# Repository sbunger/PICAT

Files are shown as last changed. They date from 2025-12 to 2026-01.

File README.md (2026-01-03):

# PICAT
PiCat is a custom devboard created with help from HackClub! The board is completely custom, running on an RP2040 and is connected to 16MB of flash memory and two 5mm LEDs that can be controlled. PCBs were created in KICAD and renders were created using Blender (renders have out of date silkscreen, but should otherwise be identical to the pcb).

I created this project gain experience working on PCBs while creating a product I will use. I plan to use at least one of the two devboards as an LED controller in a 3d printed lamp, and the other one will be used for a future project. 

The devboard can be controlled through circuitpython and arduino. Right now, I am using circuitpython to make two LEDs blink (example file in code folder).

## Photos!

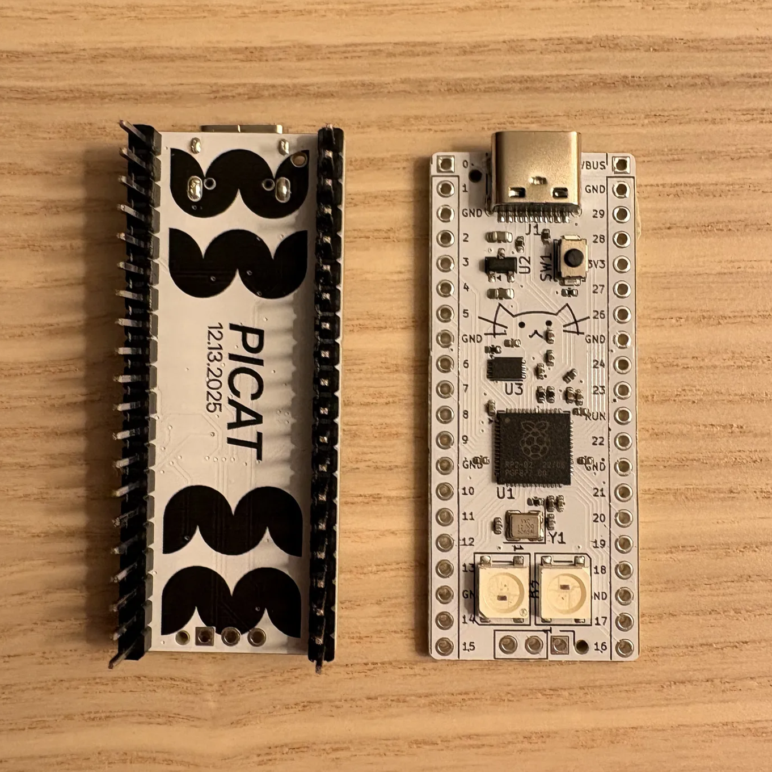
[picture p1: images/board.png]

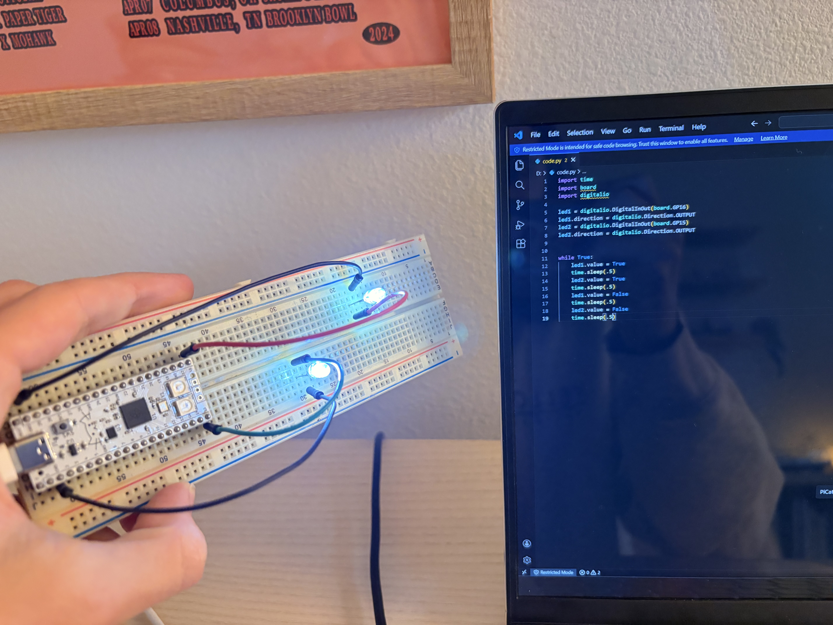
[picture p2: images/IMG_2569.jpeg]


## PCB and Schematics
PCBs were created competely by hand in KICAD.

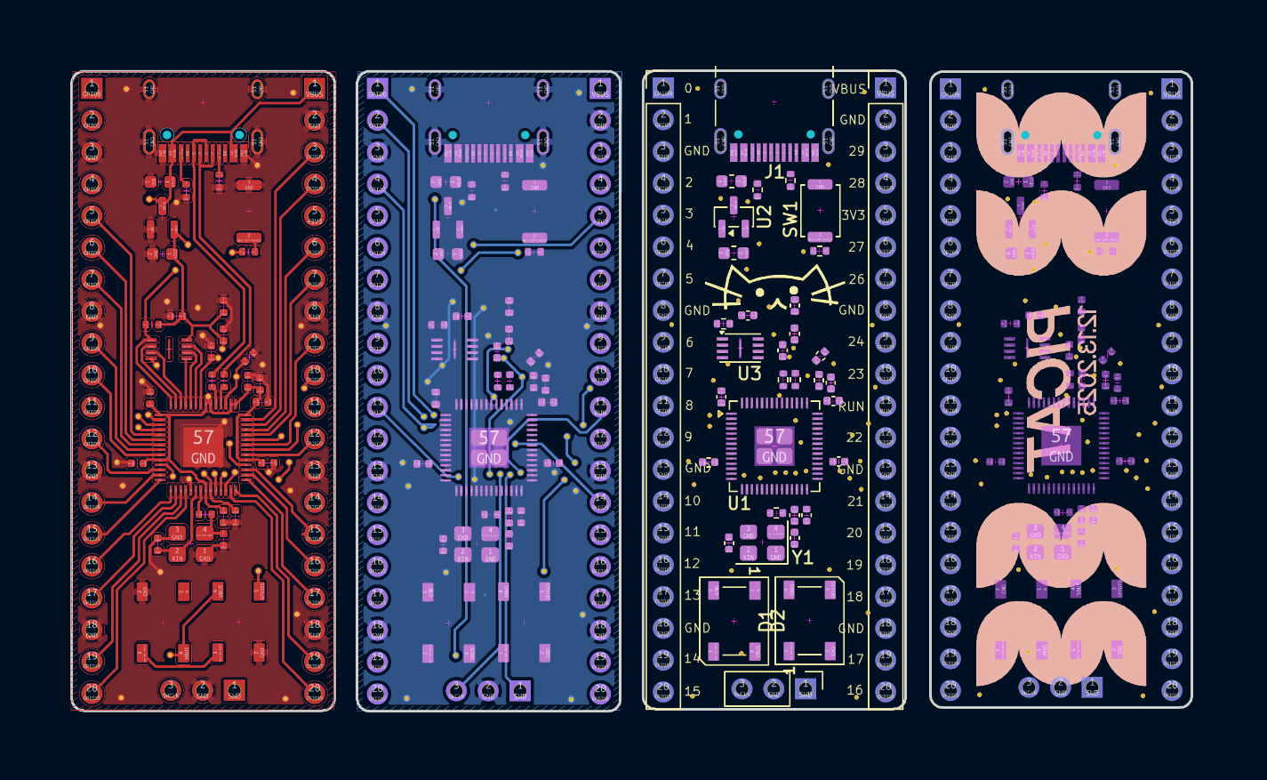
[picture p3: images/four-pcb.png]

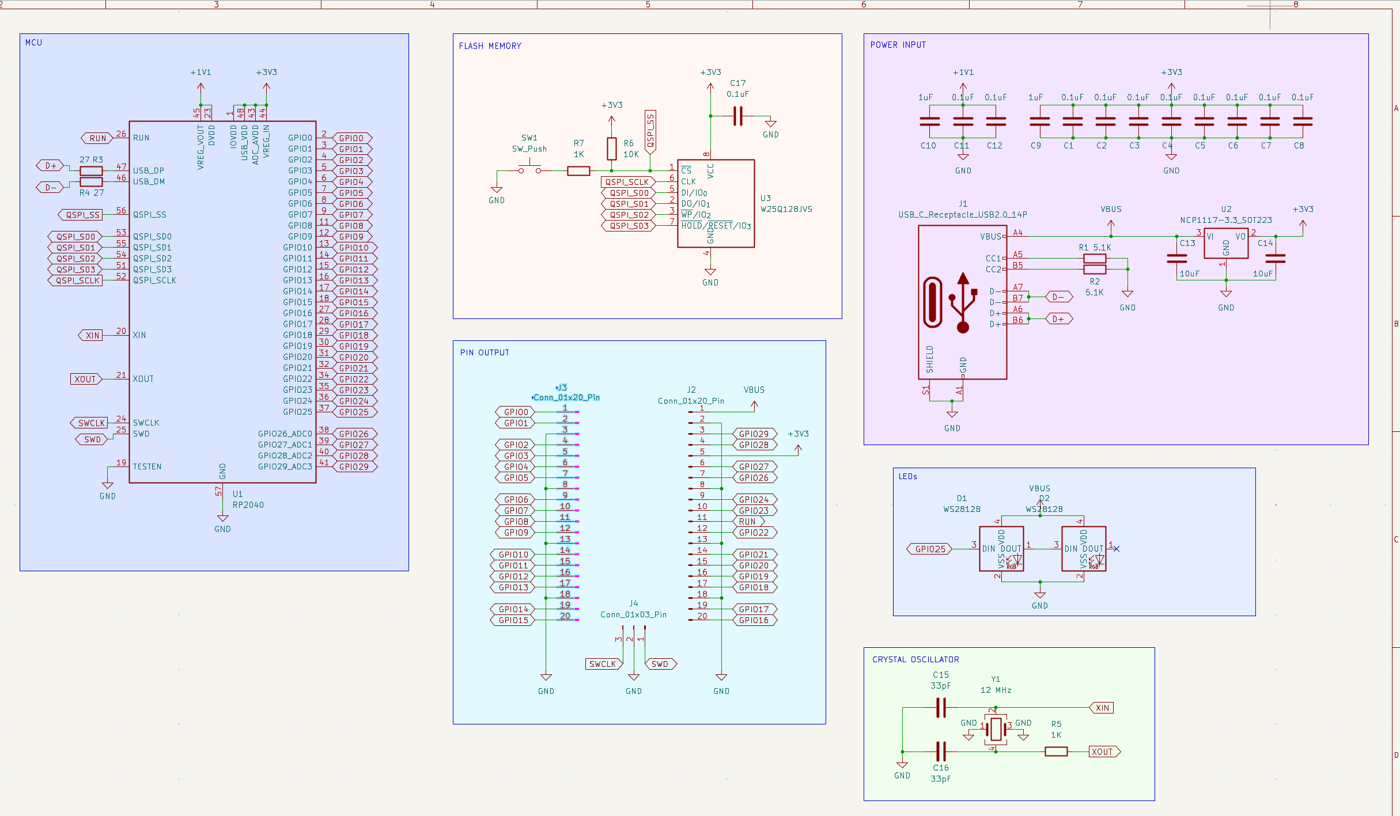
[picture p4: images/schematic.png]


## Renders

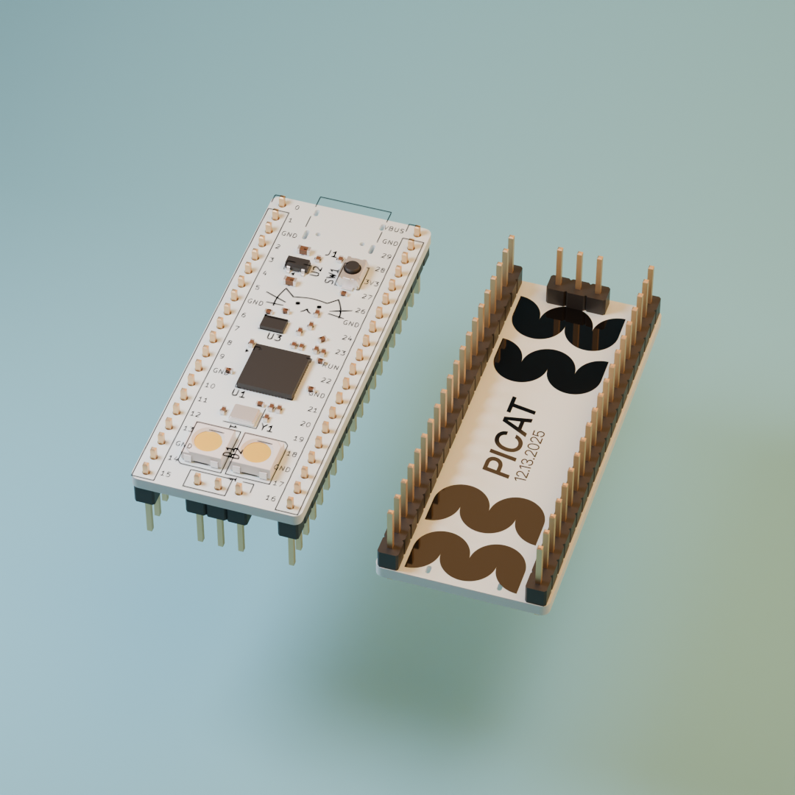
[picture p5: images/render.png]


## BOM
| Product Name | Link | Quantity | Total Cost (Tax Included) | 
| - | - | - | - |
| JLCPCB | <a href="https://jlcpcb.com/">https://jlcpcb.com/</a> | 5x PCB, 2x PCBA | $55.63 |
| 3x1 Pin Headers (Male) | <a href="https://www.aliexpress.us/item/3256806916819038.html">https://www.aliexpress.us/item/3256806916819038.html</a> | 1 Lot (10pc) | $2.93 |
| 20x1 Pin Headers (Male) | <a href="https://www.aliexpress.us/item/2255800867206912.html">https://www.aliexpress.us/item/2255800867206912.html</a> | 1 Lot (20pc) | $2.74 |
| - | - | Total Cost: | $61.3 (US) |

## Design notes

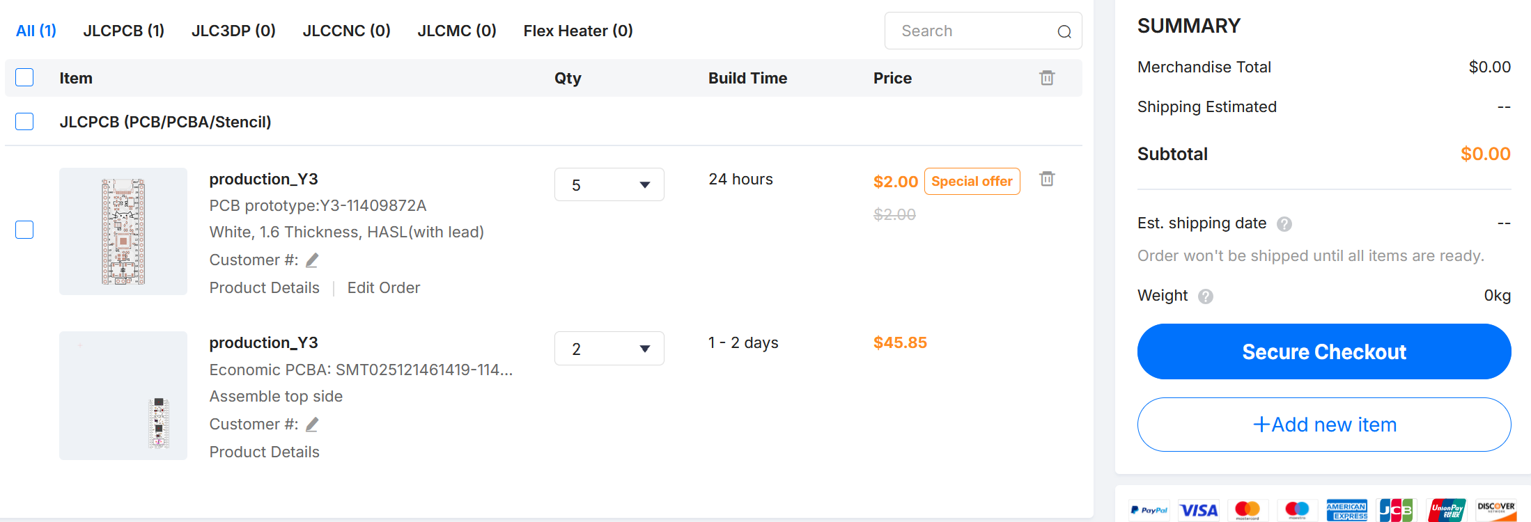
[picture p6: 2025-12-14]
images/recipts/jlc-no-shipping.png

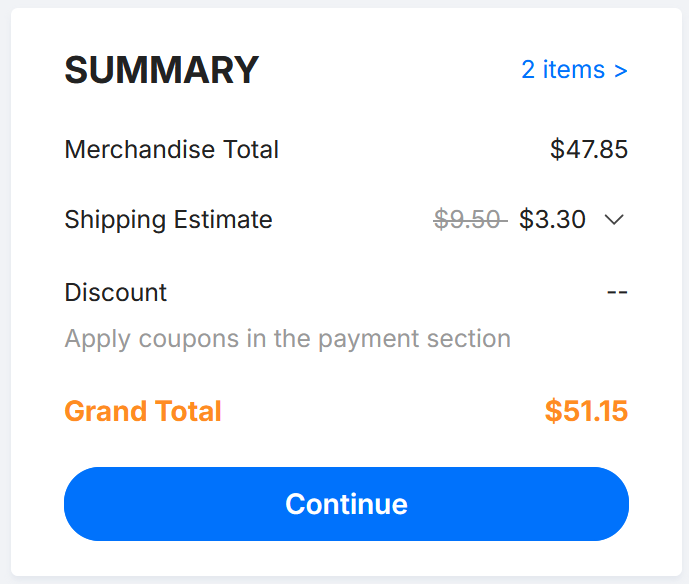
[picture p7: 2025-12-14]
images/recipts/jlc-shipping.png

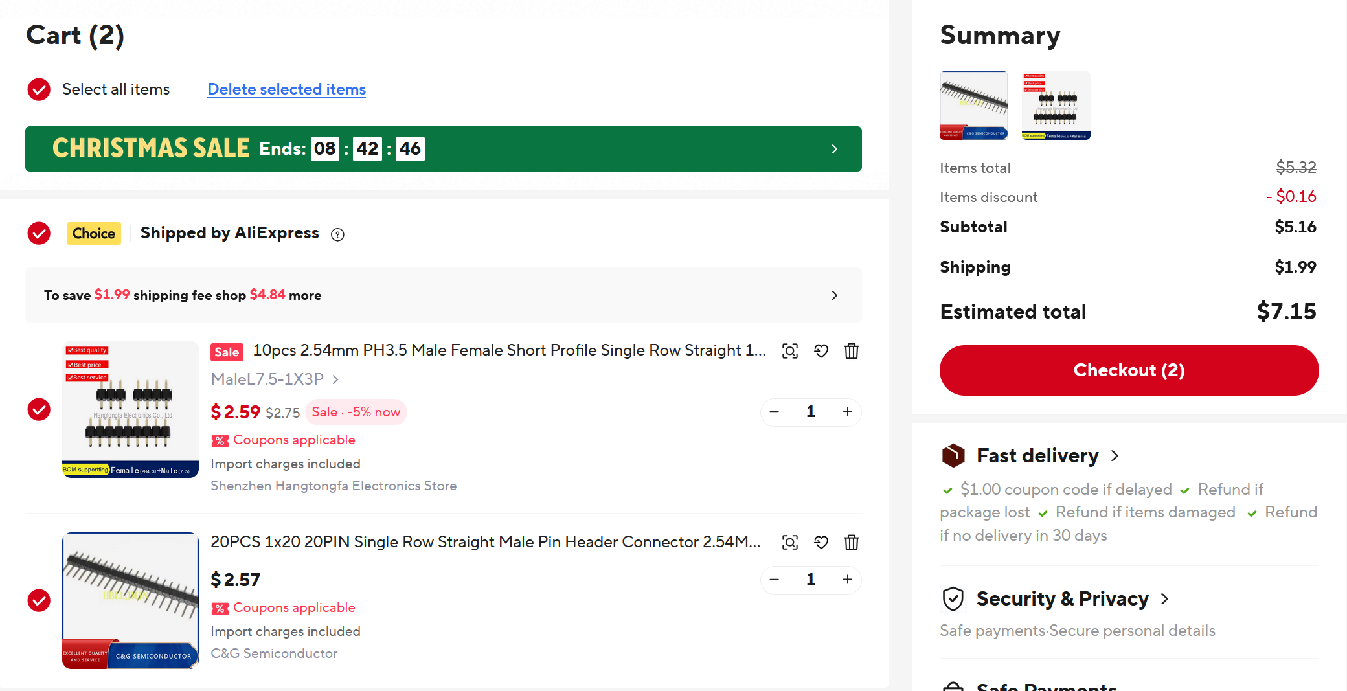
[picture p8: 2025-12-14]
images/recipts/aliexpress-headers.png

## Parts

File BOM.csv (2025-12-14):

Product Name | Product Link | Total Cost (US) | Amount | Cost With Tax | Running Total: (US)
JLC PCBA | https://jlcpcb.com/ | 49.91 | 5 PCB, 2 PCBA | 55.63 | 61.3
3x1 Pin Headers (Male) | https://www.aliexpress.us/item/3256806916819038.html | 2.75 | 1 Lot (10pc.) | 2.93
20x1 Pin Headers (Male) | https://www.aliexpress.us/item/2255800867206912.html | 2.57 | 1 Lot (20pc.) | 2.74

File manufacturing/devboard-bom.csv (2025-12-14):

Id | Designator | Footprint | Quantity | Comment | Supplier and ref
1 | D2,D1 | LED_WS2812B_PLCC4_5.0x5.0mm_P3.2mm | 2 | WS2812B
2 | U1 | QFN-56-1EP_7x7mm_P0.4mm_EP3.2x3.2mm | 1 | RP2040
3 | C10,C9 | C_0402_1005Metric | 2 | 1uF
4 | R5,R7 | R_0402_1005Metric | 2 | 1K
5 | C4,C11,C8,C1,C3,C7,C5,C6,C17,C2,C12 | C_0402_1005Metric | 11 | 0.1uF
6 | U2 | SOT-23 | 1 | NCP1117-3.3_SOT223
7 | R2,R1 | R_0402_1005Metric | 2 | 5.1K
8 | Y1 | Crystal_SMD_3225-4Pin_3.2x2.5mm_MOD | 1 | 12 MHz
9 | U3 | Winbond_USON-8-1EP_3x2mm_P0.5mm_EP0.2x1.6mm | 1 | W25Q128JVS
10 | SW1 | SW_Push_SPST_NO_Alps_SKRK | 1 | SW_Push
11 | R4,R3 | R_0402_1005Metric | 2 | 27
12 | C16,C15 | C_0402_1005Metric | 2 | 33pF
13 | J1 | USB_C_Receptacle_HRO_TYPE-C-31-M-12 | 1 | USB_C_Receptacle_USB2.0_14P
14 | R6 | R_0402_1005Metric | 1 | 10K
15 | C14,C13 | C_0603_1608Metric | 2 | 10uF
16 | J4 | PinHeader_1x03_P2.54mm_Vertical | 1 | Conn_01x03_Pin
17 | J2,J3 | PinHeader_1x20_P2.54mm_Vertical | 2 | Conn_01x20_Pin

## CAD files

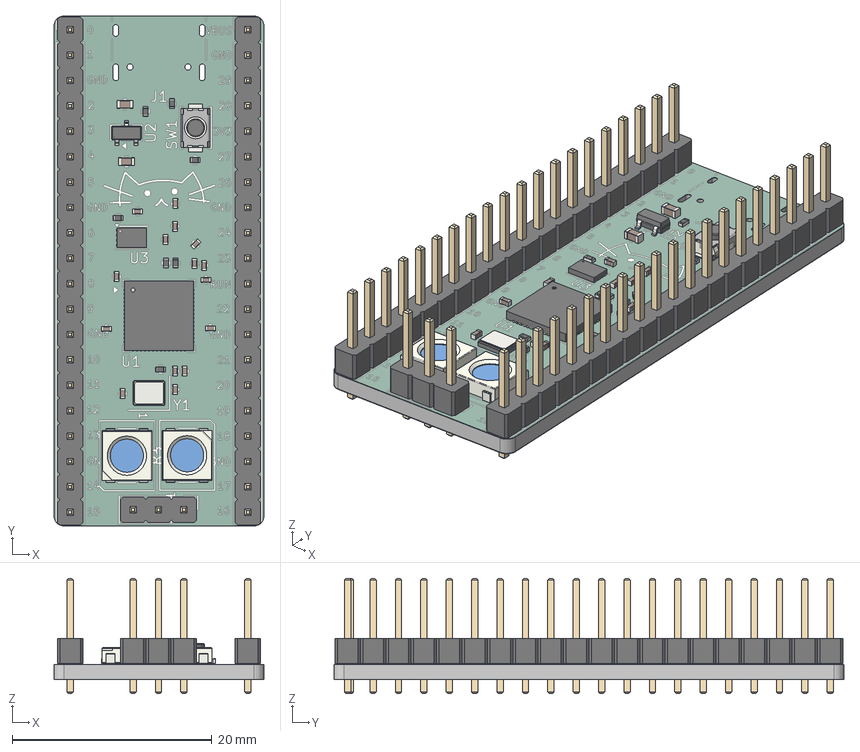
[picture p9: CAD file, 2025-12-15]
devboard-pcb/devboard.step
21.0 x 51.0 x 11.5 mm
QFN-56-1EP_7x7mm_P0.4mm_EP3.2x3.2mm
C_0402_1005Metric x 15
R_0402_1005Metric x 7
SOT-23
LED_WS2812B_PLCC4_5.0x5.0mm_P3.2mm x 2
Crystal_SMD_3225-4Pin_3.2x2.5mm
Winbond_USON-8-1EP_3x2mm_P0.5mm_EP0.2x1.6mm
SW_Push_SPST_NO_Alps_SKRK
C_0603_1608Metric x 2
PinHeader_1x03_P2.54mm_Vertical
PinHeader_1x20_P2.54mm_Vertical x 2
devboard_silkscreen x 2
devboard_soldermask x 2
devboard_PCB

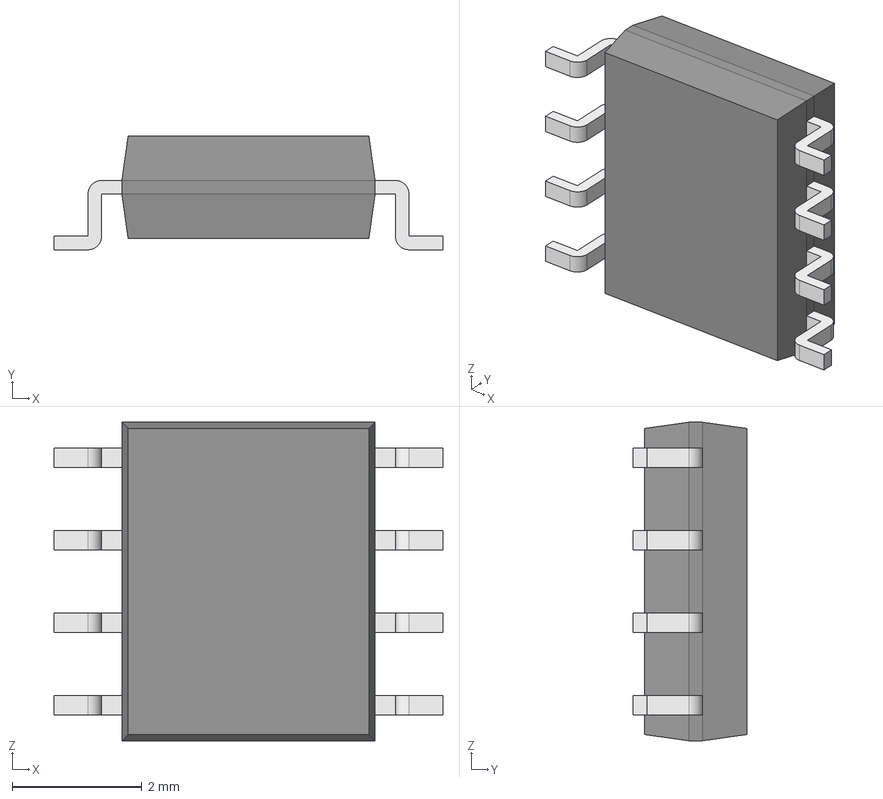
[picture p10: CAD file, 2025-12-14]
devboard-pcb/LM35DMX_NOPB/LM35DMX_NOPB.step
5.99 x 1.75 x 4.91 mm
Body001 (Mirror #1) x 4
XY-plane x 12
X-axis x 12

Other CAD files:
blender/devboard.blend

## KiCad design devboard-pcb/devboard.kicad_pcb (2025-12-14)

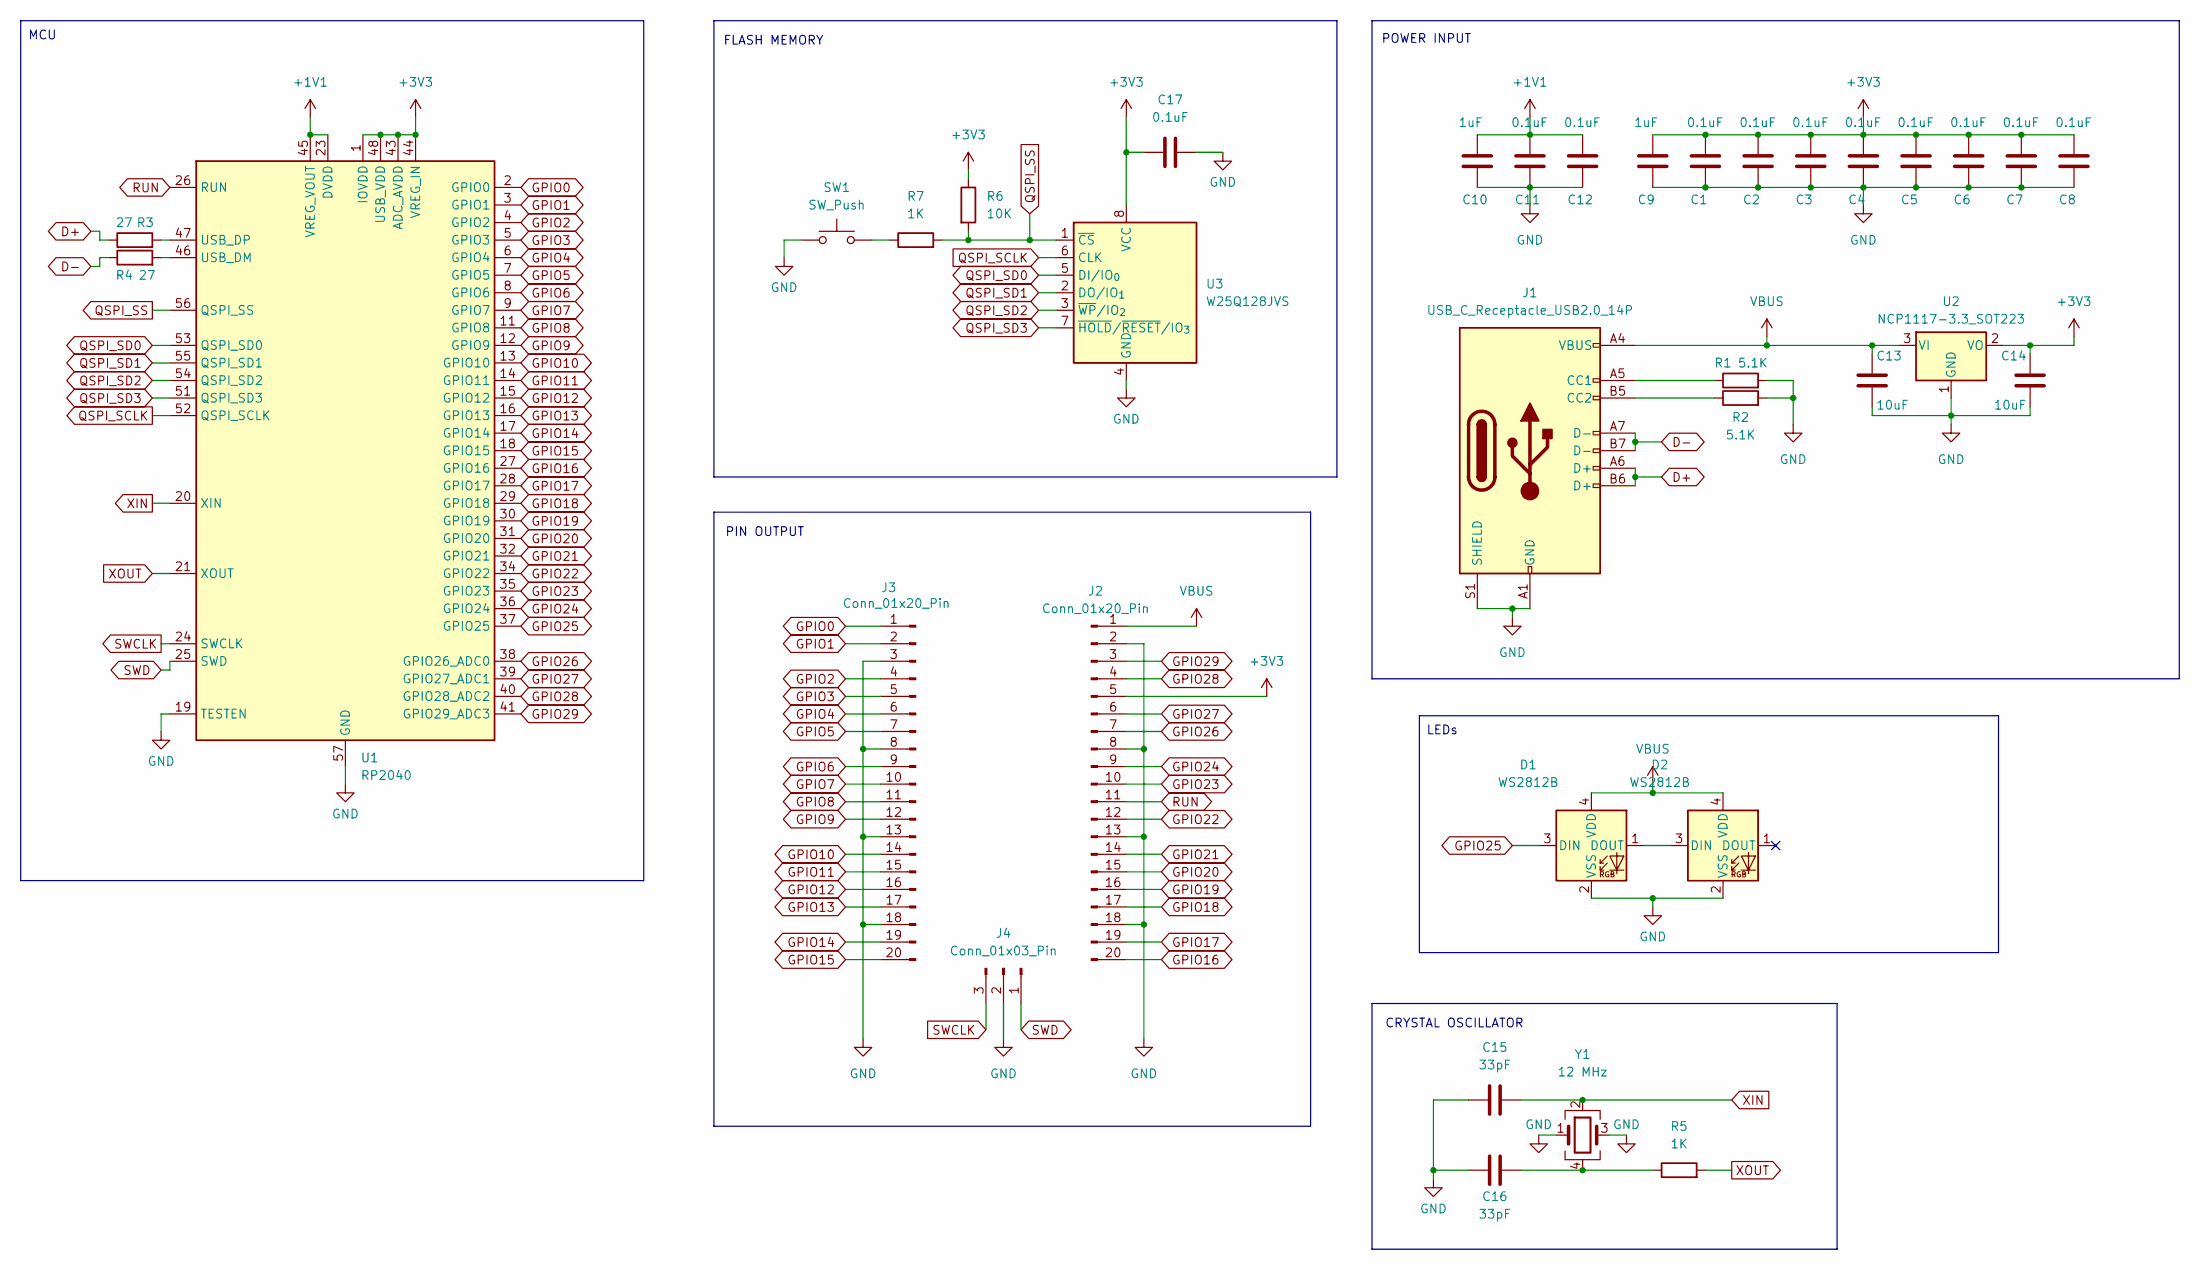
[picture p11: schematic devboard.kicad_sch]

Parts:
C1, C2, C3, C4, C5, C6, C7, C8, C11, C12, C17: 0.1uF; C_0402_1005Metric
C9, C10: 1uF; C_0402_1005Metric
C13, C14: 10uF; C_0603_1608Metric
C15, C16: 33pF; C_0402_1005Metric
D1, D2: WS2812B; LED_WS2812B-2020_PLCC4_2.0x2.0mm
J1: USB_C_Receptacle_USB2.0_14P; USB_C_Receptacle_HRO_TYPE-C-31-M-12
J2, J3: Conn_01x20_Pin; PinHeader_1x20_P2.54mm_Vertical
J4: Conn_01x03_Pin; PinHeader_1x03_P2.54mm_Vertical
R1, R2: 5.1K; R_0402_1005Metric
R3, R4: 27; R_0402_1005Metric
R5, R7: 1K; R_0402_1005Metric
R6: 10K; R_0402_1005Metric
SW1: SW_Push; SW_Push_SPST_NO_Alps_SKRK
U1: RP2040; QFN-56-1EP_7x7mm_P0.4mm_EP3.2x3.2mm
U2: NCP1117-3.3_SOT223; SOT-23
U3: W25Q128JVS; Winbond_USON-8-1EP_3x2mm_P0.5mm_EP0.2x1.6mm
Y1: 12 MHz; Crystal_SMD_3225-4Pin_3.2x2.5mm

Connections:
+1V1: C10.1, C11.1, C12.1, U1.23 (DVDD), U1.45 (VREG_VOUT), U1.50 (DVDD)
+3V3: C1.1, C2.1, C3.1, C4.1, C5.1, C6.1, C7.1, C8.1, C9.1, C14.1, C17.1, J2.5, R6.1, U1.1 (IOVDD), U1.10 (IOVDD), U1.22 (IOVDD), U1.33 (IOVDD), U1.42 (IOVDD), U1.43 (ADC_AVDD), U1.44 (VREG_IN), U1.48 (USB_VDD), U1.49 (IOVDD), U2.2 (VO), U3.8 (VCC)
D+: J1.A6 (D+), J1.B6 (D+), R3.1
D-: J1.A7 (D-), J1.B7 (D-), R4.1
GND: C1.2, C2.2, C3.2, C4.2, C5.2, C6.2, C7.2, C8.2, C9.2, C10.2, C11.2, C12.2, C13.2, C14.2, C15.1, C16.1, C17.2, D1.2 (VSS), D2.2 (VSS), J1.A1 (GND), J1.A12 (GND), J1.B1 (GND), J1.B12 (GND), J1.S1 (SHIELD), J2.2, J2.8, J2.13, J2.18, J3.3, J3.8, J3.13, J3.18, J4.2, R1.2, R2.2, SW1.1, U1.19 (TESTEN), U1.57 (GND), U2.1 (GND), U3.4 (GND), Y1.1, Y1.3
GPIO0: J3.1, U1.2 (GPIO0)
GPIO1: J3.2, U1.3 (GPIO1)
GPIO2: J3.4, U1.4 (GPIO2)
GPIO3: J3.5, U1.5 (GPIO3)
GPIO4: J3.6, U1.6 (GPIO4)
GPIO5: J3.7, U1.7 (GPIO5)
GPIO6: J3.9, U1.8 (GPIO6)
GPIO7: J3.10, U1.9 (GPIO7)
GPIO8: J3.11, U1.11 (GPIO8)
GPIO9: J3.12, U1.12 (GPIO9)
GPIO10: J3.14, U1.13 (GPIO10)
GPIO11: J3.15, U1.14 (GPIO11)
GPIO12: J3.16, U1.15 (GPIO12)
GPIO13: J3.17, U1.16 (GPIO13)
GPIO14: J3.19, U1.17 (GPIO14)
GPIO15: J3.20, U1.18 (GPIO15)
GPIO16: J2.20, U1.27 (GPIO16)
GPIO17: J2.19, U1.28 (GPIO17)
GPIO18: J2.17, U1.29 (GPIO18)
GPIO19: J2.16, U1.30 (GPIO19)
GPIO20: J2.15, U1.31 (GPIO20)
GPIO21: J2.14, U1.32 (GPIO21)
GPIO22: J2.12, U1.34 (GPIO22)
GPIO23: J2.10, U1.35 (GPIO23)
GPIO24: J2.9, U1.36 (GPIO24)
GPIO25: D1.3 (DIN), U1.37 (GPIO25)
GPIO26: J2.7, U1.38 (GPIO26_ADC0)
GPIO27: J2.6, U1.39 (GPIO27_ADC1)
GPIO28: J2.4, U1.40 (GPIO28_ADC2)
GPIO29: J2.3, U1.41 (GPIO29_ADC3)
unnamed: C16.2, R5.1, Y1.4
unnamed: D1.1 (DOUT), D2.3 (DIN)
unnamed: J1.A5 (CC1), R1.1
unnamed: J1.B5 (CC2), R2.1
unnamed: R7.1, SW1.2
unnamed: R4.2, U1.46 (USB_DM)
unnamed: R3.2, U1.47 (USB_DP)
QSPI_SCLK: U1.52 (QSPI_SCLK), U3.6 (CLK)
QSPI_SD0: U1.53 (QSPI_SD0), U3.5 (DI/IO_{0})
QSPI_SD1: U1.55 (QSPI_SD1), U3.2 (DO/IO_{1})
QSPI_SD2: U1.54 (QSPI_SD2), U3.3 (~WP/IO_{2})
QSPI_SD3: U1.51 (QSPI_SD3), U3.7 (~HOLD/~RESET/IO_{3})
QSPI_SS: R6.2, R7.2, U1.56 (QSPI_SS), U3.1 (~CS)
RUN: J2.11, U1.26 (RUN)
SWCLK: J4.3, U1.24 (SWCLK)
SWD: J4.1, U1.25 (SWD)
VBUS: C13.1, D1.4 (VDD), D2.4 (VDD), J1.A4 (VBUS), J1.A9 (VBUS), J1.B4 (VBUS), J1.B9 (VBUS), J2.1, U2.3 (VI)
XIN: C15.2, U1.20 (XIN), Y1.2
XOUT: R5.2, U1.21 (XOUT)

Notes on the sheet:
POWER INPUT
FLASH MEMORY
PIN OUTPUT
MCU
LEDs
CRYSTAL OSCILLATOR

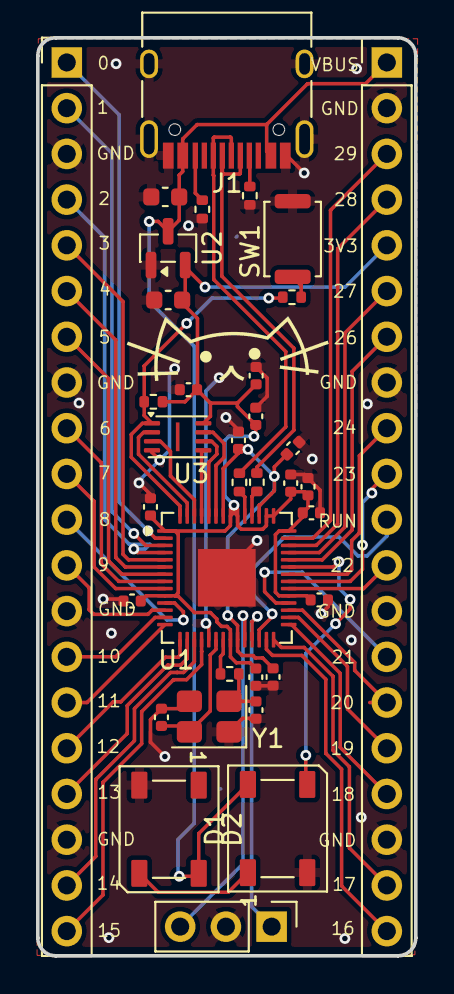
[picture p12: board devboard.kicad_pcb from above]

Board: 2 copper layers, 21.0 x 51.0 mm, 35 parts (0 on the bottom side), 54 nets.

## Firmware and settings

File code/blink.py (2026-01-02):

import time
import board
import digitalio

led1 = digitalio.DigitalInOut(board.GP16)
led1.direction = digitalio.Direction.OUTPUT
led2 = digitalio.DigitalInOut(board.GP15)
led2.direction = digitalio.Direction.OUTPUT


while True:
    led1.value = True   
    time.sleep(.5)    
    led2.value = True
    time.sleep(.5)
    led1.value = False 
    time.sleep(.5)    
    led2.value = False
    time.sleep(.5)

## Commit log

2025-12-14 Uploaded All Files
    [BOM.csv, LM35DMX_NOPB.step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]
2025-12-15 Updated Renders, blend file
    [devboard.blend, devboard.step]
2025-12-16 Blender file added
    [devboard.blend]
2026-01-02 Update README with control methods for devboard
    Added information about controlling the devboard with CircuitPython and Arduino.
